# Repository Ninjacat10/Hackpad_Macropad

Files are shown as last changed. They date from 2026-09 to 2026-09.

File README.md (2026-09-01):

# Productivity Pad

A 6-key macropad with a rotary encoder, built for the [Hack Club Hackpad](https://hackpad.hackclub.com/) program.

## Overview

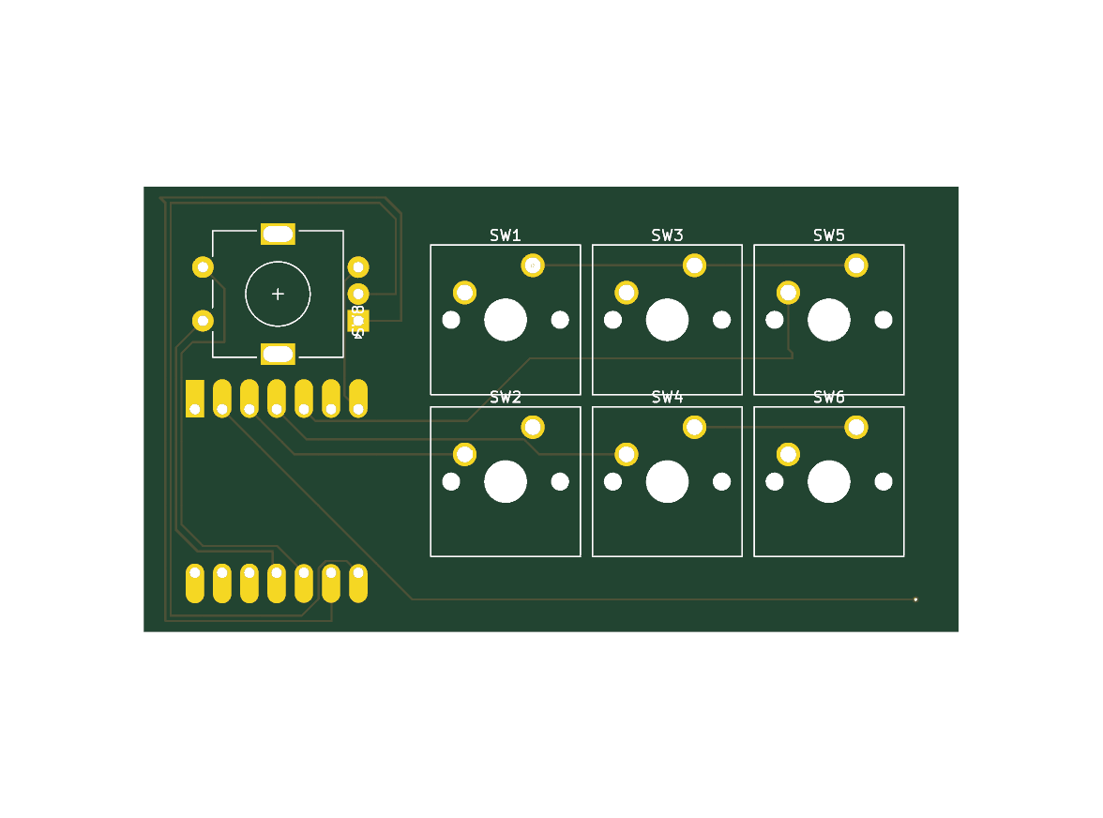
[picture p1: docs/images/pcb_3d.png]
PCB 3D render


## Schematic

Schematic

## PCB

PCB top layer

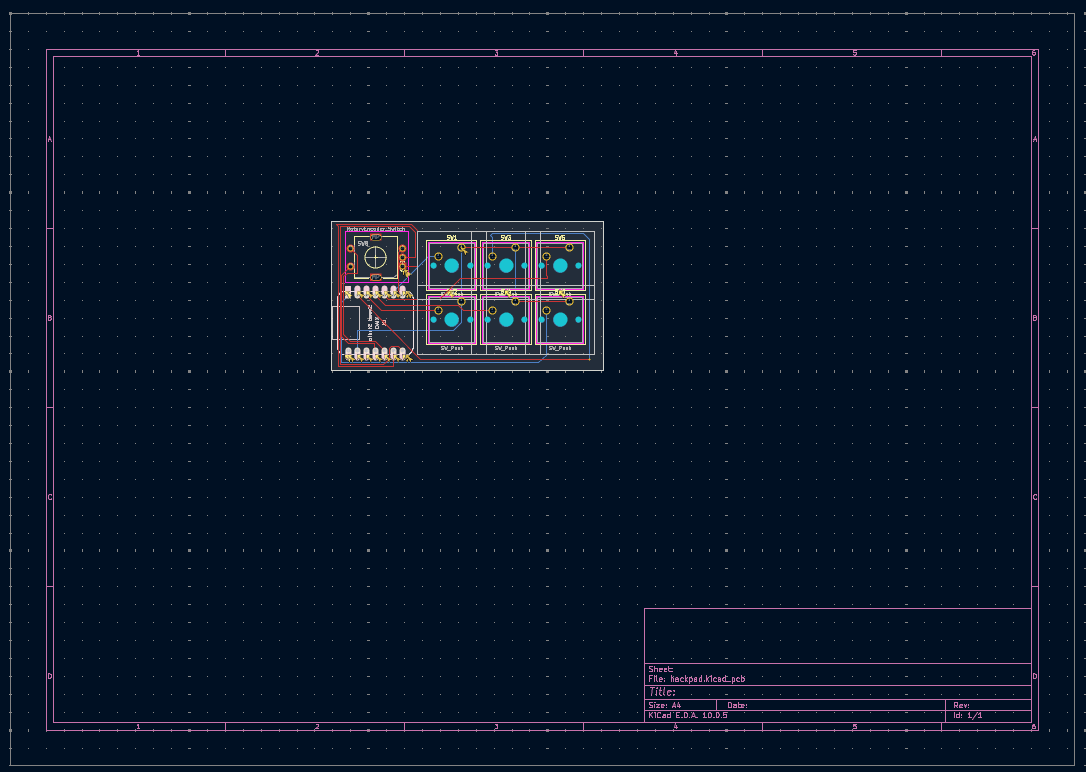
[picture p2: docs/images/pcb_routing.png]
PCB routing


## Case

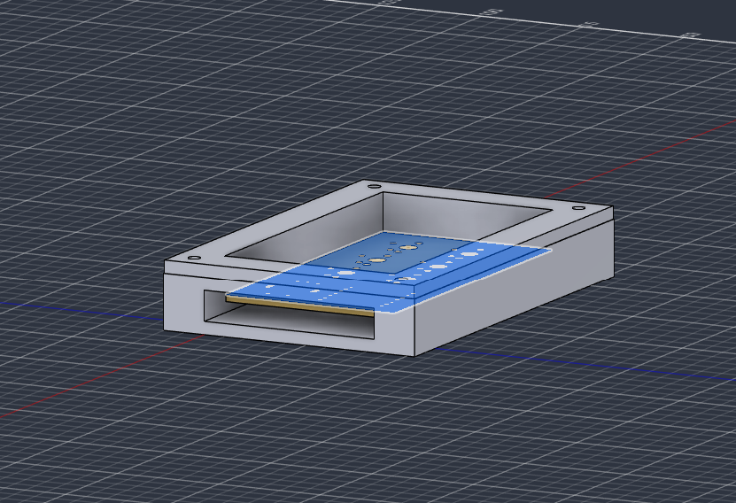
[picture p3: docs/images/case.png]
Case


Single-piece, fully 3D printed case (`CAD/hackpad_assembly.step`).

## Bill of Materials

| Ref | Part | Footprint | Qty |
|-----|---|---|-----|
| SW1-SW6 | Cherry MX-style switch | `SW_Cherry_MX_1.00u_PCB` | 6 |
| SW8 | Rotary encoder (w/ push switch) | `RotaryEncoder_Alps_EC11E-Switch_Vertical_H20mm` | 1 |
| U1 | Seeeduino XIAO | `XIAO-Generic-Hybrid-14P-2.54-21X17.8MM` | 1 |

Full generated BOM: [production/bom.csv](production/bom.csv)

## Firmware

Runs [KMK](https://github.com/KMKfw/kmk_firmware) on the Seeeduino XIAO. Keys are direct-wired to GPIO pins (no diode matrix). See [Firmware/main.py](Firmware/main.py) for the pin mapping (extracted from the schematic) and keymap.

## Repo structure

```
CAD/        complete case CAD (assembly + individual parts)
PCB/        KiCad project (schematic, PCB, project files)
Firmware/   KMK firmware source
production/ manufacturing files: gerbers.zip, PCB.step, bom.csv
docs/       README images
```

## Building it yourself

1. Order the PCB using [production/gerbers.zip](production/gerbers.zip)
2. 3D print / laser cut the case from [CAD/](CAD/)
3. Flash [Firmware/main.py](Firmware/main.py) to the XIAO via KMK/CircuitPython
4. Assemble and solder switches per the BOM above

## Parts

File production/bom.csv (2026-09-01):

Reference | Value | Footprint | Qty
SW1-SW6 | SW_Push | Button_Switch_Keyboard:SW_Cherry_MX_1.00u_PCB
SW8 | RotaryEncoder_Switch | Rotary_Encoder:RotaryEncoder_Alps_EC11E-Switch_Vertical_H20mm
U1 | MOUDLE-SEEEDUINO-XIAO | footprints:XIAO-Generic-Hybrid-14P-2.54-21X17.8MM

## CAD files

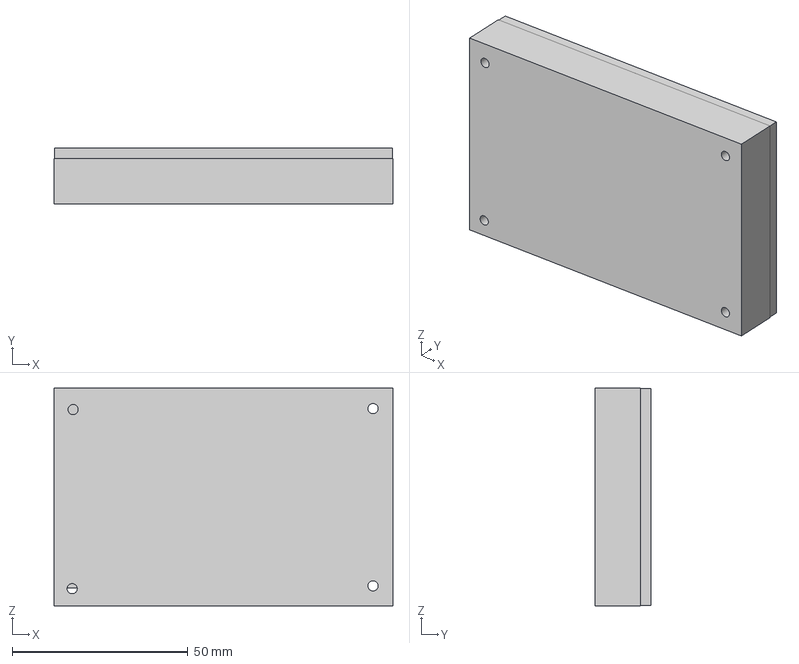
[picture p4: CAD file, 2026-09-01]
CAD/hackpad_assembly.step
96.4 x 16.0 x 61.9 mm

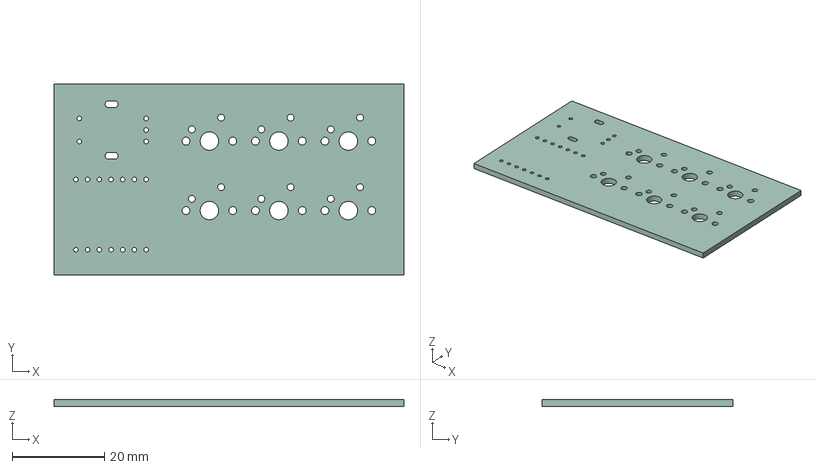
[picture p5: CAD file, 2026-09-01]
production/PCB.step
76.0 x 41.5 x 1.51 mm

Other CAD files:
CAD/hackpad_case.stl

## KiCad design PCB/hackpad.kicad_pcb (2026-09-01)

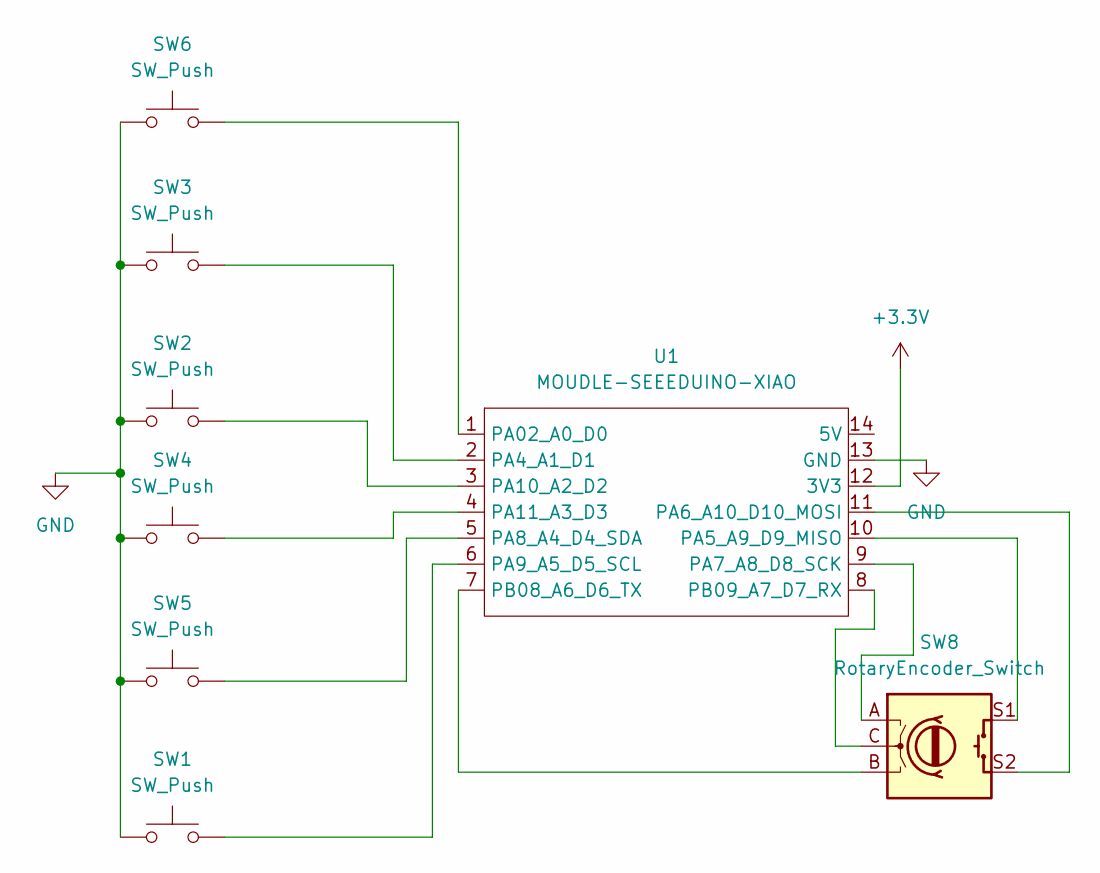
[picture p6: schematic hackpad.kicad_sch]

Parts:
SW1, SW2, SW3, SW4, SW5, SW6: SW_Push; SW_Cherry_MX_1.00u_PCB
SW8: RotaryEncoder_Switch; RotaryEncoder_Alps_EC11E-Switch_Vertical_H20mm
U1: MOUDLE-SEEEDUINO-XIAO; XIAO-Generic-Hybrid-14P-2.54-21X17.8MM

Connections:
+3.3V: U1.12 (3V3)
GND: SW1.1, SW2.1, SW3.1, SW4.1, SW5.1, SW6.1, U1.13 (GND)
unnamed: SW6.2, U1.1 (PA02_A0_D0)
unnamed: SW3.2, U1.2 (PA4_A1_D1)
unnamed: SW8.S1, U1.10 (PA5_A9_D9_MISO)
unnamed: SW8.S2, U1.11 (PA6_A10_D10_MOSI)
unnamed: SW8.A, U1.9 (PA7_A8_D8_SCK)
unnamed: SW5.2, U1.5 (PA8_A4_D4_SDA)
unnamed: SW1.2, U1.6 (PA9_A5_D5_SCL)
unnamed: SW2.2, U1.3 (PA10_A2_D2)
unnamed: SW4.2, U1.4 (PA11_A3_D3)
unnamed: SW8.B, U1.7 (PB08_A6_D6_TX)
unnamed: SW8.C, U1.8 (PB09_A7_D7_RX)

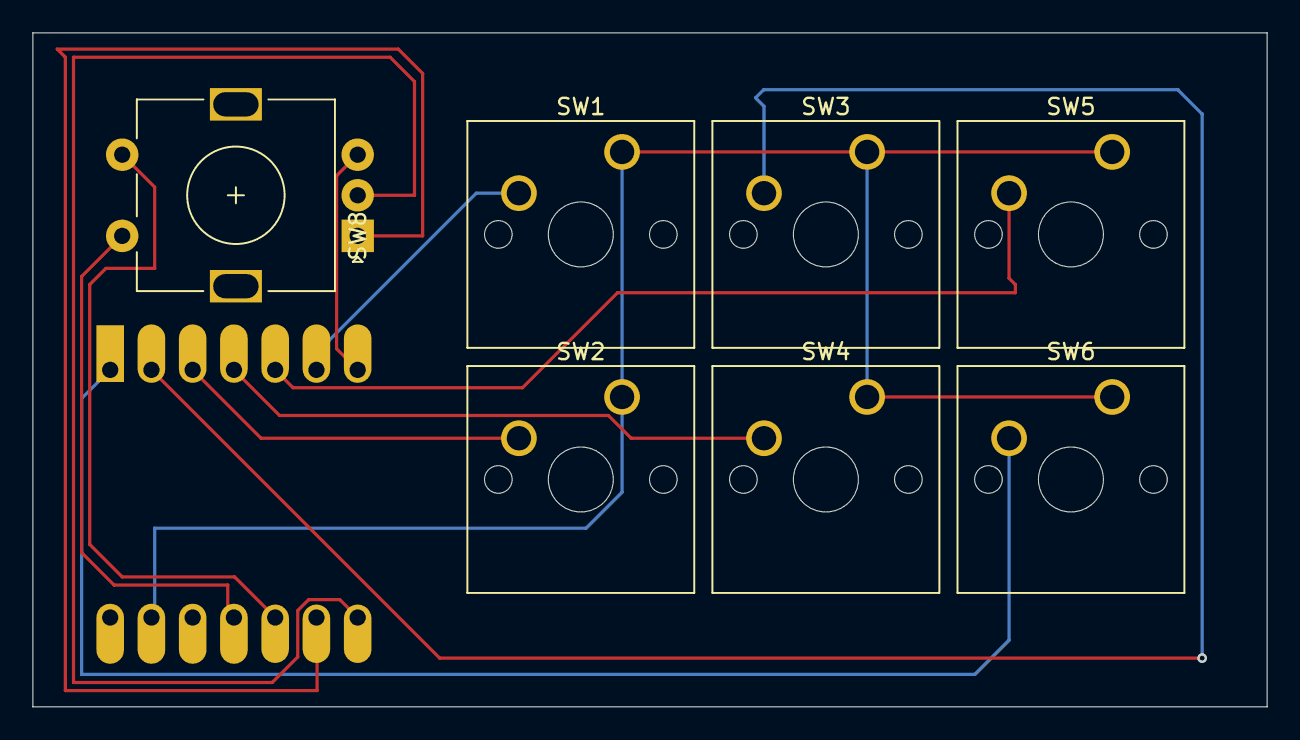
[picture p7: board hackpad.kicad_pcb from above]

Board: 2 copper layers, 76.0 x 41.5 mm, 8 parts (1 on the bottom side), 12 nets.

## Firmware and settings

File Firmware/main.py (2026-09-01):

"""
KMK firmware for hackpad (Seeeduino XIAO, direct-wired keys — no matrix).

Pin mapping was extracted directly from PCB/hackpad.kicad_sch (net list):
  SW1 -> D5 (SCL)      SW4 -> D3
  SW2 -> D2             SW5 -> D4 (SDA)
  SW3 -> D1             SW6 -> D0
  SW8 (rotary encoder): A -> D8 (SCK), B -> D6 (TX), C -> D7 (RX)
                         push-switch S1 -> D9 (MISO), S2 -> D10 (MOSI)

All SW1-SW6 pin 1 legs go to GND, so keys are wired GPIO -> GND directly
(no diode matrix), hence KMK's direct pin map is used instead of matrix scan.

NOTE: the rotary encoder's push-switch (S1/S2) is wired between two GPIOs
rather than GPIO-to-GND in this design. Double check that's intentional
before assuming the encoder click works as a normal button.
"""
import board

from kmk.kmk_keyboard import KMKKeyboard
from kmk.keys import KC
from kmk.modules.encoder import EncoderHandler
from kmk.scanners import DiodeOrientation

keyboard = KMKKeyboard()

# Direct-wired pins (no matrix / no diodes)
keyboard.col_pins = (board.D5, board.D2, board.D1, board.D3, board.D4, board.D0)
keyboard.row_pins = (board.D9,)  # dummy single row required for direct pin scanning
keyboard.diode_orientation = DiodeOrientation.COLUMNS

# Keymap: one row of 6 keys, matching SW1..SW6 order above
keyboard.keymap = [
    [KC.LCTL(KC.C), KC.LCTL(KC.V), KC.LCTL(KC.Z), KC.LCTL(KC.Y), KC.LCTL(KC.S), KC.MUTE]
    # SW1: Copy   SW2: Paste   SW3: Undo   SW4: Redo   SW5: Save   SW6: Mute
]

# Rotary encoder (SW8): A=D8, B=D6. Turning it adjusts volume.
encoder_handler = EncoderHandler()
encoder_handler.pins = ((board.D8, board.D6, None),)  # (pin_a, pin_b, button_pin)
encoder_handler.map = [((KC.VOLU, KC.VOLD),)]
keyboard.modules.append(encoder_handler)

if __name__ == '__main__':
    keyboard.go()

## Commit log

2026-09-01 Initial hackpad submission: CAD, PCB, firmware, production files
    [Case.stl, PCB.step, Plate.dxf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]
2026-09-01 Set productivity keymap: copy/paste/undo/redo/save/mute + volume encoder
2026-09-01 Add case assembly STEP and screenshot; drop duplicate view exports
    [Case.step, Case.stl, hackpad_assembly.step]
2026-09-01 Rename project to Productivity Pad; remove laser-cut plate (case must be fully 3D printed)
    [Plate.dxf, plate-2026-08-31T23_31_38.326Z.dxf]
2026-09-01 Update case screenshot to show PCB fit inside the shell
2026-09-01 Add full-routing PCB screenshot to README
